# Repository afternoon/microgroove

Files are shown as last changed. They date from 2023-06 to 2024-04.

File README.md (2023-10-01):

# Microgroove

8-track open-source hardware MIDI sequence generator.

- Machines offer different ways to generate sequences: random melodies, Euclidean rhythms, rhythms 
  from Mutable Instruments' Grids.
- Tweak parameters to explore new ideas, or to perform live.
- Quantize melodies to scales.
- Add swing and groove.
- Create interplay between sequences, like call-and-response, or ABAC structures.

## Why?

The modular world has some amazing tools to create interesting sequences: Turing Machine, Mutable
Instruments Grids, Mimetic Digitalis, Knight's Gallop, and so many more. The software ecosystem does
too, plugins like Stepic, modules in VCV Rack, and so many Max for Live experiments. In the desktop
MIDI hardware world, we're short on options (kudos to the Torso T1 for changing that), and that's
where I like to jam. I built Microgroove to bring some interesting sequencing ideas into a desktop
MIDI setup.

Microgroove is also a platform for experimentation. Trying new sequencing ideas is fast: create a
software change, flash it to the device next to you and start playing. Open sourcing the entire
device means anyone can extend or adapt it.

## Caution

Microgroove is a DIY electronic device that connects to other hardware. Please be careful if you're
working on the electronics yourself, or connecting to expensive equipment. I can't guarantee that
Microgroove won't break your gear.

## Quickstart

Connect at least one instrument to MIDI out, for example, a synth or a drum machine.

Connect a device with a sequencer to MIDI in. Microgroove doesn't have its own clock or transport
controls. It expects another device to be the master clock.

Microgroove's Track 1 is set to MIDI channel 1 by default. Set one of your instruments to listen to 
this channel, or change it from the track page.

Press play on your master sequencer. Microgroove will start playing a
randomly-generated 8-step sequence on MIDI channel 1.

Microgroove's MIDI out provides soft MIDI thru. Any MIDI notes coming from your
master sequencer will also be sent to your instruments.

### Tweak

Microgroove's philosophy is that generating a sequence and tweaking it is a
great way to create ideas. Use `[ENCODER1]` to `[ENCODER6]` to change
parameters. Use the `[TRACK]`, `[RHYTHM]` and `[MELODY]` buttons to change
between parameter pages. Press `[TRACK]` to cycle between the Track and
Sequence pages, `[RHYTHM]` to cycle between Rhythm and Groove pages, `[MELODY]`
for Melody and Harmony pages.

Each page lets you control an aspect of the current track, or the overall sequence.

- Track: Change rhythm and melody machines, length, time division and MIDI
  channel for the current track. Use `[ENCODER3]` to switch between tracks.
- Sequence: Set swing for all tracks (MPC format).
- Rhythm: Parameters for the selected rhythm machine.
- Groove: Set a part for this track, masking areas of the pattern.
- Melody: Parameters for the selected melody machine.
- Harmony: Quantize the melody to scale and key.

Choose rhythm and melody machines for each track, both are random by default.

To switch tracks, press `[TRACK]` to go to the Track page and choose a track
with `[ENCODER3]`. Tracks 2-8 are disabled by default. Choose a MIDI channel to
enable them.

Parts allow you to set up multiple tracks to play together in structures like
call-and-response or ABAC. Try setting Track 1 to `CALL` and Track 2 to
`RESP`, with all other parameters the same.

## Hardware

Microgroove is a simple device based around the Raspberry Pi Pico microcontroller. Building your own
should be straightforward (I knew nothing about electronics before I built it). The parts are fairly
standard and easy to get hold of from a few different electronics vendors, for example Pi Hut in the
UK or Adafruit in the US, and many more. You can build the device on a breadboard, or solder to
something like a [protoboard](https://www.adafruit.com/product/4785) and mount inside a laser-cut
case.

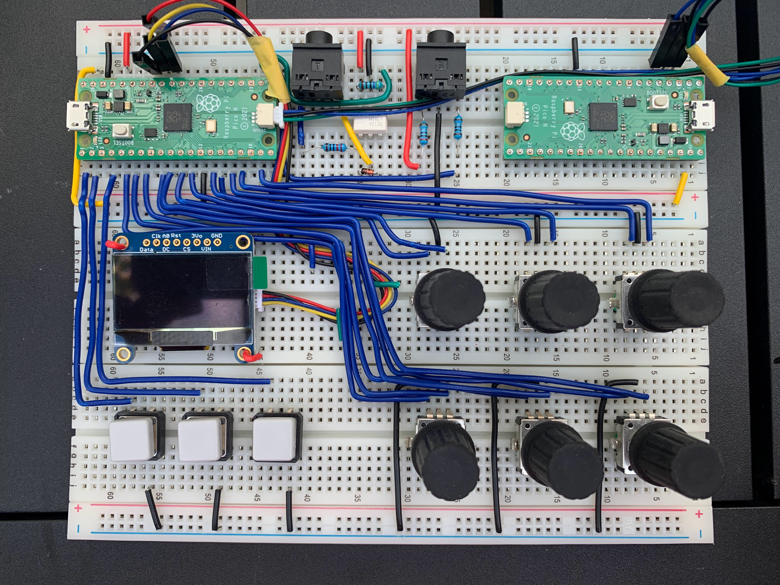
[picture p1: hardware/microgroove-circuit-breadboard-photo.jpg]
Early Microgroove build on a breadboard


### Components

| Component | Quantity |
|--- | --- |
| [Raspberry Pi Pico](https://www.raspberrypi.com/products/raspberry-pi-pico/) | 1 |
| [Adafruit 128x64 1.3" Monochrome OLED](https://www.adafruit.com/product/938) | 1 |
| [Cherry MX-compatible key](https://thepihut.com/products/kailh-mechanical-key-switches-clicky-white-10-pack) | 4 |
| [Cherry MX keycap](https://thepihut.com/products/relegendable-plastic-keycaps-for-mx-compatible-switches-5-pack) | 4 |
| [PEC11R rotary encoders](https://www.digikey.co.uk/en/products/detail/bourns-inc/PEC11R-4215F-S0024/4499665) | 6 |
| [TRS minijacks](https://thepihut.com/products/breadboard-friendly-3-5mm-stereo-headphone-jack) | 2 |
| [H11L1 optoisolator](https://www.digikey.co.uk/en/products/detail/onsemi/H11L1TVM/401266) | 1 |
| [1N914 diode](https://www.digikey.co.uk/en/products/detail/onsemi/1N914/978749) | 1 |
| 470Ω resistor | 1 |
| 220Ω resistor | 1 |
| 33Ω resistor | 1 |
| 10Ω resistor | 1 |
| Breadboard/protoboard | 2 |

### Build

This diagram shows the breadboard layout for Microgroove.

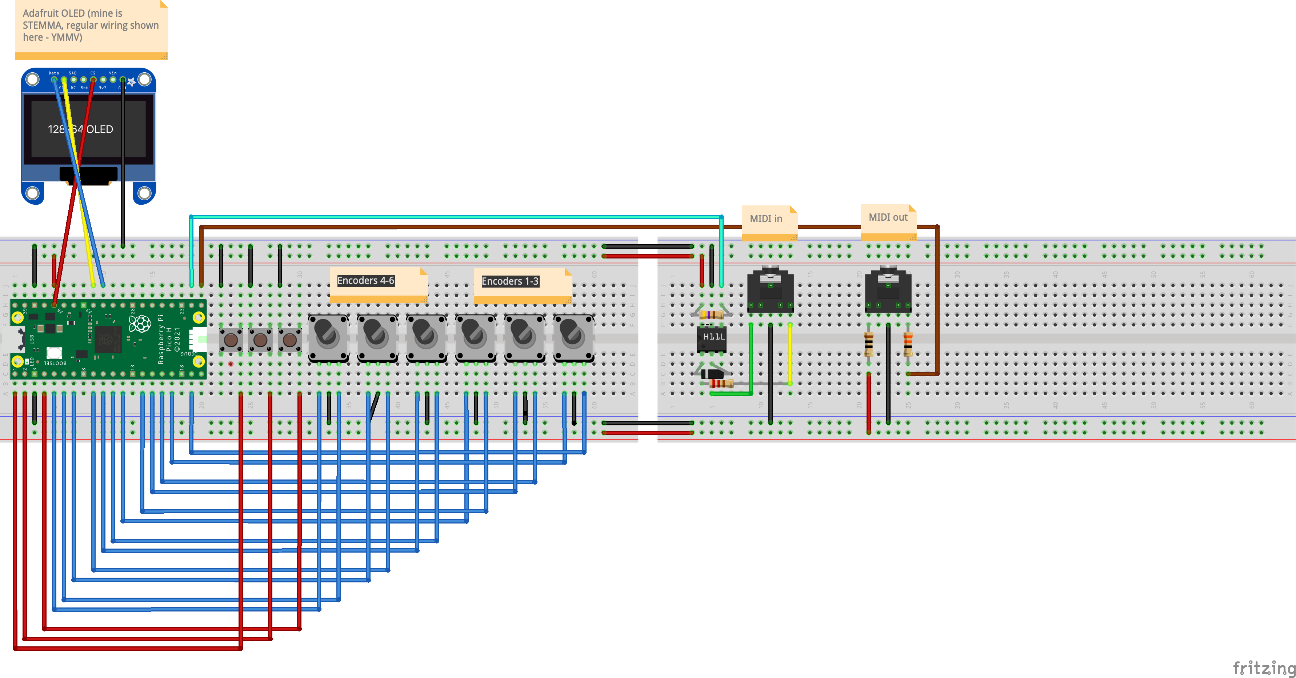
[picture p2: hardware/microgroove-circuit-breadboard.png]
Microgroove components shown on a breadboard


(If you want to build on a breadboard, you can get the Pico H, which has headers soldered on and
slots right on.)

See the [Fritzing
file](https://github.com/afternoon/microgroove/blob/main/hardware/microgroove-circuit.fzz) to view
the components and their connections. There is also a schematic view, but it is currently a mess.

The OLED display, keys and encoders connect directly to pins on the Pico.

The MIDI section is also fairly simple. They are based on diyelectromusic's
[MIDI in](https://diyelectromusic.wordpress.com/2021/02/15/midi-in-for-3-3v-microcontrollers/) and
[MIDI out](https://diyelectromusic.wordpress.com/2021/01/23/midi-micropython-and-the-raspberry-pi-pico/)
circuits (thanks Kevin!). You can use TRS minijacks like me, or classic MIDI DIN jacks. Either way,
check the pinouts for the components you purchase carefully. Wrong wiring here might damage your
gear.

### Case

The case is laser-cut. I used 3mm ply. You can find
the [design as an SVG file
here](https://github.com/afternoon/microgroove/blob/main/hardware/microgroove-case-lasercut.svg).

The SVG file was creating in Tinkercad. You can [access the model
here](https://www.tinkercad.com/things/e7vA3MJyz0E-microgroove-box). If you would like to make
your own modifications, you can clone the model in Tinkercad and customise it.

When cut, the case pieces slot together, and the components screw or glue to the case with 
standoffs and M2 or M3 screws.

If you don't have access to a laser cutter, you should be able to find cutting services online.

## Firmware

The Microgroove firmware is written in Rust using the [RTIC](https://rtic.rs)
real-time framework. RTIC is truly wonderful. It lets us write clean Rust code
which multitasks with timing accurate to a few microseconds.

The app loosely follows the MVC architecture. The `microgroove_sequencer` library crate implements
the model. In the `microgroove_app` binary crate, the `display` module implements the view, while
the`app` module implements the controller.

Conceptually Microgroove is inspired by Elektron's machines, which make it fast to create and
manipulate musical ideas (the UI borrows Elektron's pages + encoders paradigm), and from modular,
which allows different task-specific components to be composed into a system. Different `Machine`s
can be combined to change how the sequence is generated.

The Machine concept is somewhat inspired by modular, where different modules can generate the
rhythm or the melody, or process it.

The code is split across two crates to allow the model and logic code to be platform-independent,
and therefore testable.

### Data model

A set of `struct`s in the `microgroove_sequencer` crate implement the data model.

- The top-level object is an instance of `Sequencer`.
- A `Sequencer` has many `Track`s. `Track` has a length, time division, MIDI channel, etc, and a
  `Sequence`.
- `Sequence` is a wrapper around a `Vec` of `Step`s, providing a grammar of methods for
  manipulating sequences in useful ways, e.g. setting the note numbers for steps from a `Vec` of
  `Note`s.
- `Step` has a `Note`, velocity, length and delay.
- `Note` is an `enum` of all MIDI note numbers.

Sequence generation is implemented by the `SequenceGenerator` struct. This is exposed to the RTIC
application separately from the data model, to allow the app to control how and when concrete
sequences are generated. A `SequenceGenerator` object has two `Machine`s. One to generate the rhythm
and a second to generate a melody. `Machine`s have an `apply` method which takes a `Sequence` and
transforms it. The process of generating a sequence is implemented as a pipeline in
`SequenceGenerator::generate`. A default `Sequence` is created and transformed by several
`Machine`s in order. The `Sequence` is then passed to a quantizer and to logic which applies parts -
removing steps from parts of the sequence.

### Building the firmware

If you haven't already, [install Rust](https://www.rust-lang.org/tools/install). If you aren't yet
familiar with Rust, I recommend reading the [Rust Book](https://doc.rust-lang.org/book/) to learn
the language.

Microgroove requires Rust nightly (it uses the
[linked_list_allocator](https://crates.io/crates/linked_list_allocator) crate, which requires the
`AllocRef` trait only in the nightly API). You'll also need to install the `thumbv6m-none-eabi`
target, which allows compilation for the Pi Pico's ARM Cortex-M0+ CPU, and
[cargo-embed](https://crates.io/crates/cargo-embed) which extends `cargo` with an `embed` command to
flash binaries to embedded devices.

```
$ rustup toolchain install nightly
$ rustup target add thumbv6m-none-eabi
$ cargo install cargo-embed
```

You can check your setup by running the `microgroove_sequencer` crate's unit tests.

```
$ cd firmware/microgroove_sequencer
$ cargo test
```

Connect the Pi Pico to your computer with USB and use `cargo-embed` to flash the app to your device.

```
$ cd ../microgroove_app
$ cargo embed
```

Your Microgroove should now be ready to play!

### Debugging

Serial output will be displayed on the console. See the
[cargo-embed](https://crates.io/crates/cargo-embed) docs for information on how to run GDB.

You can also use `probe-run` to flash binaries, but this requires a debug probe (which can be a 2nd
Pi Pico).

## Get in touch

Microgroove is still young and evolving fast. I'm be really interested to help out if you would like to build a device or contribute. I'd love to get your feedback on the process and also on how the device is to play, whether it’s fun, if you find the sequences in generates useful, what would make it more useful, and so on.

If you have feedback, ideas or questions, 
head over to the [discussions section](https://github.com/afternoon/microgroove/discussions)
or contact me at [ben@ben2.com](mailto:ben@ben2.com).

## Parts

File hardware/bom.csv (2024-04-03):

Reference | Value | Datasheet | Footprint | Qty | DNP
D1 | 1N914 | http://www.vishay.com/docs/85622/1n914.pdf | Diode_THT:D_DO-35_SOD27_P7.62mm_Horizontal | 1
DS1 | NHD-2.7-12864WDW3 | https://componentsearchengine.com/Datasheets/1/NHD-2.7-12864WDW3.pdf | NHD-2.7-12864WDW3:NHD2712864WDW3 | 1
J1 | UJ2-MIBH-4-SMT-TR | https://www.cuidevices.com/product/resource/uj2-mibh-4-smt.pdf | UJ2-MIBH-4-SMT-TR:CUIDEVICES_UJ2-MIBH-4-SMT-TR | 1
J2,J3 | SJ1-3513 | https://www.cuidevices.com/product/resource/sj1-351x.pdf | SJ1_3513:CUI_SJ1-3513 | 2
R1 | 470 | ~ | Resistor_THT:R_Axial_DIN0207_L6.3mm_D2.5mm_P10.16mm_Horizontal | 1
R2 | 220 | ~ | Resistor_THT:R_Axial_DIN0207_L6.3mm_D2.5mm_P10.16mm_Horizontal | 1
R3 | 33 | ~ | Resistor_THT:R_Axial_DIN0207_L6.3mm_D2.5mm_P10.16mm_Horizontal | 1
R4 | 10 | ~ | Resistor_THT:R_Axial_DIN0207_L6.3mm_D2.5mm_P10.16mm_Horizontal | 1
SW1,SW2,SW3,SW4,SW5,SW6 | RotaryEncoder | https://www.bourns.com/docs/Product-Datasheets/PEC11R.pdf | PEC11R_4215F_S0024:XDCR_PEC11R-4215F-S0024 | 6
SW7,SW8,SW9,SW10,SW11 | TL1100F160Q6JBLK | TL1100F160Q6JBLK | footprints:SW4_TL1100F160Q6JBLK_EWI | 5
U1 | Pico | https://datasheets.raspberrypi.com/pico/pico-datasheet.pdf | MCU_RaspberryPi_and_Boards:RPi_Pico_SMD_TH | 1
U2 | H11L1 | https://www.onsemi.com/pub/Collateral/H11L3M-D.PDF | Package_DIP:DIP-6_W7.62mm | 1

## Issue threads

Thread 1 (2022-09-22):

Track param number doesn't update

afternoon, 2022-09-22:
In param table, track number is always 1.

Closed 2023-01-14.

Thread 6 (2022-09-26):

Allow arbitrary number of Params

afternoon, 2022-09-26:
Currently, each Machine has 6 Params (the number of encoders on the dev board). If fewer Params are required, they can be marked as disabled. Putting Params in e.g. a vector or a list would simplify the code and allow Machines to have more than 6 Params. In this case, the UI should support paging through the Param list, e.g. by pressing an input mode button repeatedly (the pattern used on Elektron machines).

Closed 2023-01-14.

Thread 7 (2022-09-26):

`TuringMachine` sequences do not loop correctly if length is not 16

afternoon, 2022-09-26:
`TuringMachine` should generate sequences which loop if `prob` is 0. Currently the implementation of `shift_bits()` uses all the bits of a `uint16t`, which means the sequence will only loop after 16 steps.

Expected behaviour:

1. At startup, the sequencer should generate a sequence of length `length`.
2. When the sequencer progresses, the `PROB` param should control the likelihood of the sequence changing.
3. The sequence can change at each step.
4. If the sequence changes, the UI should still show previous steps as they were played, and future steps should be updated with new values.
5. If `PROB` is at min or max, then the sequence displayed by the UI and the notes sent should be the same.
6. If `PROB` is at min or max, then the sequence should loop after `length` or `2 * length` steps.

Requirements:

1. Some way to get the full sequence (steps `0..length`).
2. Some way to get a suffix of the sequence, and write that over the invalidated suffix.
3. Some way to trigger the shifting of bits per-step.
4. The `Machine` API should be as clean and simple as possible.

Possible approaches:

1. Machine API has only `Note next()` method
   a. Track/Player implementation calls `next` `length` times to build a sequence or a sequence suffix.
   b. Pro: Simple API, Player/Track internals do the bookkeeping
   c. Con: next is destructive, subsequent calls, e.g. to generate different suffixes as params are tweaked, will change the sequence, this will be hard to predict for the user.
2. Machine API has separate methods to mutate and access the sequence (for a single note or string of notes).
   a. Pro:
   a. Con: Machine API has more methods = more work for machine implementors
   a. Con: Because bit flips are stochastic, UI will never actually display the real sequence if PROB is not at min or max.

Closed 2023-01-14.

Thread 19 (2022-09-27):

Player always plays 16 steps

afternoon, 2022-09-27:
- Need to track current step per-`Track` - `Track::tick()`?
- Must reset each `Track` from `start_playing`

Closed 2023-01-14.

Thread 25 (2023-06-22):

Integrate the NeoKey 1x4

afternoon, 2023-06-22:
[Adafruit's NeoKey 1x4](https://www.adafruit.com/product/4980) is a PCB that holds 4 Cherry MX keys and 4 NeoPixels (RGB LEDs). Clicky keys are really nice (I love the Elektron ones), colourful LEDs are really nice.

The NeoKey talks Adafruit's Seesaw protocol over I2C. The button state can be read by writing a command and then doing a read. A short pause is needed between these. Adafruit suggest 250us.

There are a couple of Seesaw crates available, but both use longer delays. This leads to the device locking up, as the key state is read every few ms. The Seesaw protocol is pretty simple, so the way to go might be to just do I2C write and read calls directly in the RTIC tasks. E.g.:

```
fn task1() {
  send_get_key_state_command();
  task2::spawn_after(READ_DELAY_US);
}

fn task2 {
  read_response();
}
```

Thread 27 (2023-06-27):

Press button to randomise

afternoon, 2023-06-27:
Currently, sequences are regenerated whenever a parameter is changed. For sequence generators which have some randomness as an input, this means that they change dramatically on each parameter change. This makes it impossible to generate a sequence and iterate upon it. For example, by cutting a 16-step sequence down to 8 steps.

It should be possible to control when regeneration happens and which elements are randomised. Some example scenarios:

1. Randomise only melody notes
2. Randomise groove (step velocities)
3. Randomise everything to start a new idea
4. Randomise only one parameter

Probably this could work as follows:

1. Go to the Melody page, press the `[RAND]` button
2. Go to the Groove page, press `[RAND]`
3. Long-press `[RAND]`
4. Hold `[RAND]` and tweak the encoder for the param(s) you want to randomise

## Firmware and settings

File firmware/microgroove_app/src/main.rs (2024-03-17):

#![no_std]
#![no_main]

mod display;
mod encoder;
mod input;
mod midi;
mod peripherals;

use panic_probe as _;

// RTIC app module runs the app as a set of concurrent tasks modifying shared state
// this module is responsible for interfacing with the hardware
#[rtic::app(
    device = rp_pico::hal::pac,
    peripherals = true,
    dispatchers = [USBCTRL_IRQ, DMA_IRQ_0, DMA_IRQ_1, PWM_IRQ_WRAP]
)]
mod app {
    use alloc_cortex_m::CortexMHeap;
    use core::fmt::Write;
    use debouncr::{debounce_8, Debouncer, Edge, Repeat8};
    use defmt::{self, debug, error, info, trace};
    use defmt_rtt as _;
    use embedded_hal::digital::v2::InputPin;
    use fugit::MicrosDurationU64;
    use heapless::{String, Vec};
    use midi_types::MidiMessage;
    use nb::block;
    use rp_pico::hal::timer::{monotonic::Monotonic, Alarm0};

    use crate::{
        display::{self, PerformView},
        encoder::encoder_array::EncoderArray,
        input::{self, InputMode},
        midi,
        peripherals::{
            setup, ButtonMelodyPin, ButtonRhythmPin, ButtonTrackPin, Display, MidiIn, MidiOut,
        },
    };
    use microgroove_sequencer::{
        machine_resources::MachineResources,
        sequence_generator::SequenceGenerator,
        sequencer::{ScheduledMidiMessage, Sequencer},
        Track, TRACK_COUNT,
    };

    #[global_allocator]
    static ALLOCATOR: CortexMHeap = CortexMHeap::empty();
    const HEAP_SIZE_BYTES: usize = 8 * 1024;

    // how often to read button state
    const BUTTON_READ_INTERVAL: MicrosDurationU64 = MicrosDurationU64::millis(5);

    // how often to poll encoders for position updates
    const ENCODER_READ_INTERVAL: MicrosDurationU64 = MicrosDurationU64::millis(2);

    // time between each display render
    // this is the practical upper bound for drawing and flushing a frame to the oled
    // at 40ms, the frame rate will be 25 FPS
    // we want the lowest frame rate that looks acceptable, to provide the largest budget for
    // render times
    const DISPLAY_UPDATE_INTERVAL: MicrosDurationU64 = MicrosDurationU64::millis(40);

    /// Define RTIC monotonic timer. Also used for defmt.
    #[monotonic(binds = TIMER_IRQ_0, default = true)]
    type TimerMonotonic = Monotonic<Alarm0>;

    /// RTIC shared resources.
    #[shared]
    struct Shared {
        current_track: u8,

        /// Sequencer big-ball-of-state
        sequencer: Sequencer,

        /// Current page of the UI.
        input_mode: InputMode,

        // set of SequenceGenerators, one for each `Track` in `Sequencer`
        sequence_generators: Vec<SequenceGenerator, TRACK_COUNT>,
    }

    /// RTIC local resources.
    #[local]
    struct Local {
        /// MIDI input port (1 half of the split UART).
        midi_in: MidiIn,

        /// MIDI output port (1 half of the split UART).
        midi_out: MidiOut,

        /// Interface to the display.
        display: Display,

        /// Pin for button the [TRACK] button
        button_track_pin: ButtonTrackPin,

        /// Pin for button the [RHYTHM] button
        button_rhythm_pin: ButtonRhythmPin,

        /// Pin for button the [MELODY] button
        button_melody_pin: ButtonMelodyPin,

        /// Debounce state for [TRACK] button
        button_track_state: Debouncer<u8, Repeat8>,

        /// Debounce state for [RHYTHM] button
        button_rhythm_state: Debouncer<u8, Repeat8>,

        /// Debounce state for [MELODY] button
        button_melody_state: Debouncer<u8, Repeat8>,

        // encoders
        encoders: EncoderArray,

        // context object for machines to use in sequence generation
        machine_resources: MachineResources,
    }

    /// RTIC init method sets up the hardware and initialises shared and local resources.
    #[init]
    fn init(ctx: init::Context) -> (Shared, Local, init::Monotonics) {
        info!("[init] hello world!");

        // initialise allocator for dynamic structures (machines, params, etc)
        unsafe {
            ALLOCATOR.init(cortex_m_rt::heap_start() as usize, HEAP_SIZE_BYTES);
            debug!(
                "[init] heap_start={} heap_size_bytes={}",
                cortex_m_rt::heap_start() as usize,
                HEAP_SIZE_BYTES
            );
        }

        // configure RTIC monotonic as source of timestamps for defmt
        defmt::timestamp!("{=u64:us}", {
            monotonics::now().duration_since_epoch().to_micros()
        });

        // create a device wrapper instance and grab some of the peripherals we need
        let (midi_in, midi_out, mut display, buttons, encoders, rosc, monotonic_timer) =
            setup(ctx.device);
        let (button_track_pin, button_rhythm_pin, button_melody_pin) = buttons;

        // create bounce state trackers for each button
        let button_track_state = debounce_8(false);
        let button_rhythm_state = debounce_8(false);
        let button_melody_state = debounce_8(false);

        // create a vec of `SequenceGenerator`s, we'll use these to generate sequences for our
        // tracks.
        let mut sequence_generators: Vec<SequenceGenerator, TRACK_COUNT> = Vec::new();
        for _i in 0..TRACK_COUNT {
            sequence_generators
                .push(SequenceGenerator::default())
                .expect("adding SequenceGenerator to vec should succeed");
        }

        // create a new sequencer and build the first track
        let mut sequencer = Sequencer::default();
        let mut generator = SequenceGenerator::default();
        let mut machine_resources = MachineResources::new(rosc);
        let mut new_track = Track::default();
        generator.generate(&mut machine_resources);
        new_track.sequence = generator.apply(new_track.length);
        sequencer.enable_track(0, new_track);

        // show a splash screen for a bit
        display::render_splash_screen_view(&mut display)
            .expect("render_splash_screen_view should succeed");

        // start scheduled tasks to read buttons, read encoders and update display
        read_buttons::spawn().expect("read_buttons::spawn should succeed");
        read_encoders::spawn().expect("read_encoders::spawn should succeed");
        update_display::spawn().expect("update_display::spawn should succeed");

        info!("[init] complete 🤘");

        (
            Shared {
                input_mode: Default::default(),
                current_track: 0,
                sequencer,
                sequence_generators,
            },
            Local {
                midi_in,
                midi_out,
                display,
                button_track_pin,
                button_rhythm_pin,
                button_melody_pin,
                button_track_state,
                button_rhythm_state,
                button_melody_state,
                encoders,
                machine_resources,
            },
            init::Monotonics(monotonic_timer),
        )
    }

    /// Handle MIDI input. Triggered by a byte being received on UART0.
    #[task(
        binds = UART0_IRQ,
        priority = 4,
        shared = [sequencer],
        local = [midi_in]
    )]
    fn uart0_irq(mut ctx: uart0_irq::Context) {
        let start = monotonics::now();
        trace!("[uart0_irq] start");

        // read those sweet sweet midi bytes!
        // TODO do we need the block! here?
        if let Ok(message) = block!(ctx.local.midi_in.read()) {
            ctx.shared.sequencer.lock(|sequencer| match message {
                MidiMessage::TimingClock => {
                    trace!("[midi] clock");
                    let now_us = monotonics::now().duration_since_epoch().to_micros();
                    let messages = sequencer.advance(now_us);
                    for message in messages {
                        match message {
                            ScheduledMidiMessage::Immediate(message) => {
                                if let Err(_err) = midi_send::spawn(message) {
                                    error!("could not spawn midi_send for immediate message")
                                }
                            }
                            ScheduledMidiMessage::Delayed(message, delay) => {
                                if let Err(_err) = midi_send::spawn_after(delay, message) {
                                    error!("could not spawn midi_send for delayed message")
                                }
                            }
                        }
                    }
                }
                MidiMessage::Start => {
                    info!("[midi] start");
                    sequencer.start_playing();
                }
                MidiMessage::Stop => {
                    info!("[midi] stop");
                    sequencer.stop_playing();
                }
                MidiMessage::Continue => {
                    info!("[midi] continue");
                    sequencer.continue_playing();
                }
                _ => trace!("[midi] UNKNOWN"),
            });

            // pass received message to midi out ("soft thru")
            match midi_send::spawn(message) {
                Ok(_) => (),
                Err(_) => error!("could not spawn midi_send to pass through message"),
            }
        }

        trace!(
            "[uart0_irq] elapsed_time={}",
            (monotonics::now() - start).to_micros()
        );
    }

    /// Send a MIDI message. Implemented as a task to allow cooperative multitasking with
    /// higher-pri tasks.
    #[task(
        priority = 3,
        capacity = 64,
        local = [midi_out]
    )]
    fn midi_send(ctx: midi_send::Context, message: MidiMessage) {
        trace!("midi_send");
        midi::log_message(&message);
        ctx.local
            .midi_out
            .write(&message)
            .expect("midi_out.write(message) should succeed");
    }

    /// Check state of buttons, debouncing inputs, and update the `input_mode` shared resource.
    #[task(
        priority = 4,
        shared = [input_mode],
        local = [button_track_pin, button_rhythm_pin, button_melody_pin, button_track_state, button_rhythm_state, button_melody_state]
    )]
    fn read_buttons(mut ctx: read_buttons::Context) {
        let start = monotonics::now();
        trace!("[read_buttons] start");

        // for each button
        let track_pressed = ctx
            .local
            .button_track_pin
            .is_low()
            .expect("should get track button state");
        let track_edge = ctx.local.button_track_state.update(track_pressed);
        if track_edge == Some(Edge::Rising) {
            info!("[TRACK] pressed");
            ctx.shared.input_mode.lock(|input_mode| {
                *input_mode = match *input_mode {
                    InputMode::Track => InputMode::Sequence,
                    _ => InputMode::Track,
                }
            });
        }

        let rhythm_pressed = ctx
            .local
            .button_rhythm_pin
            .is_low()
            .expect("should get rhythm button state");
        let rhythm_edge = ctx.local.button_rhythm_state.update(rhythm_pressed);
        if rhythm_edge == Some(Edge::Rising) {
            info!("[RHYTHM] pressed");
            ctx.shared.input_mode.lock(|input_mode| {
                *input_mode = match *input_mode {
                    InputMode::Rhythm => InputMode::Groove,
                    _ => InputMode::Rhythm,
                }
            });
        }

        let melody_pressed = ctx
            .local
            .button_melody_pin
            .is_low()
            .expect("should get melody button state");
        let melody_edge = ctx.local.button_melody_state.update(melody_pressed);
        if melody_edge == Some(Edge::Rising) {
            info!("[MELODY] pressed");
            ctx.shared.input_mode.lock(|input_mode| {
                *input_mode = match *input_mode {
                    InputMode::Melody => InputMode::Harmony,
                    _ => InputMode::Melody,
                }
            });
        }

        read_buttons::spawn_after(BUTTON_READ_INTERVAL).expect("should spawn read_buttons task");

        trace!(
            "[read_buttons] elapsed_time={}",
            (monotonics::now() - start).to_micros()
        );
    }

    /// Check encoders for position changes.
    /// Reading every 1ms removes some of the noise vs reading on each interrupt.
    #[task(
        priority = 4,
        shared = [input_mode, current_track, sequencer, sequence_generators],
        local = [encoders, machine_resources],
    )]
    fn read_encoders(ctx: read_encoders::Context) {
        let start = monotonics::now();
        trace!("[read_encoders] start");

        if let Some(_changes) = ctx.local.encoders.update() {
            (
                ctx.shared.input_mode,
                ctx.shared.current_track,
                ctx.shared.sequencer,
                ctx.shared.sequence_generators,
            )
                .lock(
                    |input_mode, current_track, sequencer, sequence_generators| {
                        input::apply_encoder_values(
                            ctx.local.encoders.take_values(),
                            *input_mode,
                            current_track,
                            sequencer,
                            sequence_generators,
                        )
                        .expect("should be able to apply encoder values");
                    },
                )
        }

        // read again in 1ms
        read_encoders::spawn_after(ENCODER_READ_INTERVAL)
            .expect("schedule read_encoders should succeed");

        trace!(
            "[read_encoders] elapsed_time={}",
            (monotonics::now() - start).to_micros()
        );
    }

    /// Update the display by rendering a view object. This method creates an instance of a view,
    /// passing in relevant data (which is copied). The view then takes care of rendering to the
    /// display. Rendering is time-consuming, because writing data across I2C is slow. Hence the
    /// work is offloaded to the `render_view` task, unlocking shared resources and allowing other
    /// tasks to interrupt the rendering.
    #[task(
        priority = 1,
        shared = [input_mode, current_track, sequencer, sequence_generators],
    )]
    fn update_display(ctx: update_display::Context) {
        let start = monotonics::now();
        trace!("[update_display] start");

        (
            ctx.shared.input_mode,
            ctx.shared.current_track,
            ctx.shared.sequencer,
            ctx.shared.sequence_generators,
        )
            .lock(
                |input_mode, current_track, sequencer, sequence_generators| {
                    let tick = sequencer.tick();
                    let maybe_track = sequencer
                        .tracks
                        .get_mut(*current_track as usize)
                        .expect("should get current track")
                        .as_mut();
                    let generator = sequence_generators
                        .get(*current_track as usize)
                        .expect("should get current sequence generator");
                    let part = generator.part();
                    let view = match maybe_track {
                        Some(track) => {
                            let sequence = Some(track.sequence.clone());
                            let active_step_num = Some(track.step_num(tick));
                            let machine_name = match input_mode {
                                InputMode::Rhythm => {
                                    Some(String::<10>::from(generator.rhythm_machine.name()))
                                }
                                InputMode::Melody => {
                                    Some(String::<10>::from(generator.melody_machine.name()))
                                }
                                _ => None,
                            };
                            let params = match input_mode {
                                InputMode::Track => track.params(),
                                InputMode::Sequence => sequencer.params(),
                                InputMode::Rhythm => generator.rhythm_machine.params(),
                                InputMode::Groove => generator.groove_params(),
                                InputMode::Melody => generator.melody_machine.params(),
                                InputMode::Harmony => generator.harmony_params(),
                            };
                            let param_data = Some(
                                params
                                    .iter()
                                    .map(|param| {
                                        let mut value_string = String::new();
                                        write!(value_string, "{}", param.value())
                                            .expect("should write param value to string buf");
                                        (String::<6>::from(param.name()), value_string)
                                    })
                                    .collect(),
                            );
                            PerformView {
                                input_mode: *input_mode,
                                playing: sequencer.playing(),
                                track_num: *current_track,
                                sequence,
                                part,
                                active_step_num,
                                machine_name,
                                param_data,
                            }
                        }
                        None => PerformView {
                            input_mode: *input_mode,
                            playing: sequencer.playing(),
                            track_num: *current_track,
                            sequence: None,
                            part,
                            active_step_num: None,
                            machine_name: None,
                            param_data: None,
                        },
                    };

                    render_view::spawn(view).expect("should be able to spawn_after display_update");
                },
            );

        update_display::spawn_after(DISPLAY_UPDATE_INTERVAL)
            .expect("should be able to spawn_after update_display");

        trace!(
            "[update_display] elapsed_time={}",
            (monotonics::now() - start).to_micros()
        );
    }

    #[task(
        priority = 1,
        local = [display]
    )]
    fn render_view(ctx: render_view::Context, view: PerformView) {
        let start = monotonics::now();
        trace!("[render_view] start");

        if let Err(_) = view.render(ctx.local.display) {
            error!("PerformView::render error");
        }

        trace!(
            "[render_view] elapsed_time={}",
            (monotonics::now() - start).to_micros()
        );
    }

    // idle task needed because default RTIC idle task calls wfi(), which breaks rtt
    // TODO disable in release mode
    #[idle]
    fn task_main(_: task_main::Context) -> ! {
        loop {
            cortex_m::asm::nop();
        }
    }
}

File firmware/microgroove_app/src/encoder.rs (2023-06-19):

pub mod positional_encoder {
    use core::fmt::Debug;
    use defmt::{error, trace};
    use rotary_encoder_hal::{Direction, Rotary};
    use rp_pico::hal::gpio::DynPin;

    pub struct PositionalEncoder {
        encoder: Rotary<DynPin, DynPin>,
        value: i8,
    }

    impl PositionalEncoder {
        pub fn new(mut pin_a: DynPin, mut pin_b: DynPin) -> PositionalEncoder {
            pin_a.into_pull_up_input();
            pin_b.into_pull_up_input();
            PositionalEncoder {
                encoder: Rotary::new(pin_a.into(), pin_b.into()),
                value: 0,
            }
        }

        /// Check the encoder state for changes. This should be called frequently, e.g.
        /// every 1ms. Returns a `Some` containing the encoder value if there have been
        /// changes, `None` otherwise.
        pub fn update(&mut self) -> Option<i8> {
            match self.encoder.update() {
                Ok(Direction::Clockwise) => {
                    trace!("[PositionalEncoder::update] Direction::Clockwise");
                    self.value += 1;
                    Some(self.value)
                }
                Ok(Direction::CounterClockwise) => {
                    trace!("[PositionalEncoder::update] Direction::CounterClockwise");
                    self.value -= 1;
                    Some(self.value)
                }
                Ok(Direction::None) => None,
                Err(_error) => {
                    error!("[PositionalEncoder::update] could not update encoder");
                    None
                }
            }
        }

        /// Get the value of the encoder, and then reset that to zero. This has the
        /// semantics of "I would like to know your value, which I will use to update my
        /// state, so you can then discard it."
        pub fn take_value(&mut self) -> Option<i8> {
            let value = self.value;
            if value == 0 {
                None
            } else {
                self.value = 0;
                Some(value)
            }
        }
    }

    impl Debug for PositionalEncoder {
        fn fmt(&self, f: &mut core::fmt::Formatter<'_>) -> core::fmt::Result {
            write!(f, "encoder")
        }
    }
}

pub mod encoder_array {
    use super::positional_encoder::PositionalEncoder;
    use heapless::Vec;

    pub const ENCODER_COUNT: usize = 6;

    /// An array of multiple `PositionalEncoders`.
    pub struct EncoderArray {
        encoders: Vec<PositionalEncoder, ENCODER_COUNT>,
    }

    impl EncoderArray {
        pub fn new(encoders: Vec<PositionalEncoder, ENCODER_COUNT>) -> EncoderArray {
            EncoderArray { encoders }
        }

        pub fn update(&mut self) -> Option<()> {
            let any_changes = self
                .encoders
                .iter_mut()
                .map(|enc| enc.update())
                .any(|opt| opt.is_some());
            if any_changes {
                Some(())
            } else {
                None
            }
        }

        pub fn take_values(&mut self) -> Vec<Option<i8>, ENCODER_COUNT> {
            self.encoders
                .iter_mut()
                .map(|enc| enc.take_value())
                .collect()
        }
    }
}

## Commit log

2022-10-14 Use trunk versions of rp-pico and rp2040-hal
2022-10-16 Track interval between MIDI ticks and use it to calculate note lengths
2022-10-17 PoC to render some stuff on an SSD1306-powered OLED display
2022-10-23 Change pins around, read buttons and encoders in ISR
2022-10-27 Switch to rotary-encoder-hal table-decoder version, fixes multiple increments
    [main.rs]
2022-10-31 Read all 6 encoders
2022-11-01 [1/n] Root causing failing button interrupts
    [main.rs]
2022-11-01 Revert main.rs to "spaghetti" version
    I found the issue - I hadn't connected the ground rail on my breadboard,
    so button presses were not properly grounding the pins. 🤦
    [main.rs]
2022-11-01 Use rp2040's ring oscillator peripheral to generate random numbers
    [main.rs]
2022-11-04 Remove no-longer-required button_repro.rs (it was a missing ground wire)
2022-11-05 [2/n] Yak-shaving type/lifetime/borrow errors
    [main.rs]
2022-11-10 [3/3] Move device setup to a single function
    I can't figure out how to get the ownership of pac right to split setup across multiple functions. X-(
2022-11-24 Show track disabled warning (&& add warning helper)
2022-11-28 Add SequenceProcessors which generate musical sequences, Params, which translate encoder input into arguments to SequenceProcessors, and Machines, which glue those two concepts together into somethin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
2022-11-28 Add global allocator, tidy up some errors
    [main.rs]
2022-11-30 Map encoder input to track/machine params
2022-12-01 Add Track Param definitions
2022-12-01 Allow device-agnostic code to be tested by splitting code into 2 crates, one for business logic and one for hardware-specific parts, e.g. the rtic app, display code, etc
2022-12-02 Display track number in header correctly
    [main.rs]
2022-12-04 Fix REALLY STUPID bug in encoder input handling
    It always went up.
    [encoder.rs, input.rs, main.rs]
2022-12-04 Track::apply_params() regenerates sequence
2022-12-05 Increment track num correctly and create new tracks when other params change
    [encoder.rs, input.rs, lib.rs]
2022-12-05 Set MIDI channel to track number on track creation
2022-12-05 Implement Default for InputMode, TimeDivision and Track
2022-12-05 Show current machine name in header
2022-12-05 Remove Track::new() and tidy up test names
2022-12-06 Fix bug in calculation of average tick duration (and thus tempo)
    [input.rs]
2022-12-06 MIDI channel is 0-indexed in track and 1-indexed in params 🤷
2022-12-07 Offload display rendering to a 2nd task, unlocking resources and making encoder and button reading and MIDI _FUCKIN TIGHT_
    [encoder.rs, input.rs, lib.rs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]
2022-12-07 Reorder track speed param values to be more natural
2022-12-15 Almost a rewrite...
    Introduce a new kind of machine which generates a random sequence...
    Which meant rewriting the Sequencer/Track/Machine structure to allow an
    RNG to be passed...
    Which required some conditional compilation to provide access to
    platform-specific RNGs...
    Which didn't require rewriting params, but honestly I had started that
    first and couldn't face unpicking the changes.
    Probably other stuff I've forgotten.
    [input.rs, lib.rs, main.rs]
2022-12-19 Fix off-by-one error in midi channel param handler
    [lib.rs]
2022-12-19 RandMelodyMachine generates notes in the specified range
    And add in the missing F#8 note! Eeeek.
    [lib.rs]
2022-12-19 Only reset machines if machine params have changed
    [input.rs]
2022-12-20 Euclidean. Groove. Machine. 🤘
2022-12-23 Add quantizer params to a 2nd page when pressing [MELODY]
    Also create 2nd pages for the [TRACK] and [RHYTHM] buttons, for global and groove params respectively. Will be used later for stuff like swing.
2022-12-23 Debounce button presses (so we can land on a specific param page reliably)
2023-01-13 Add a part param, which can be used to mute sections of a track, such that multiple tracks can be composed into structures like call and response, or ABAC
2023-06-19 Replace unwrap with expect in a bunch of places, and cargo fmt
    [encoder.rs, input.rs, main.rs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]
2023-06-19 Remove the alloc error handler, its no longer needed
    [main.rs]
2023-06-19 Move Rust firmware source to firmware subdirectory, create hardware subdir and add case and circuit diagrams
    [microgroove-circuit.fzz]
2023-06-20 Add photo of my breadboard prototype Microgroove
2023-06-20 [README] Show photo of my breadboard prototype Microgroove
2023-06-22 [README] Tidy up hardware build instructions and add BOM
    [microgroove-circuit.fzz]
2023-06-22 [README] Add keys and keycaps to BOM
2023-10-01 Remove NeoKey from docs and designs. It is dead to me.
    [microgroove-circuit.fzz]
2024-03-17 Add KiCAD schematic for v1.1 circuit (TRS Type A, PINs moved around for more PCB-friendly layout, hopefully)
    [microgroove.kicad_pcb, microgroove.kicad_sch]
2024-03-17 Ignore KiCAD's footprint cache file
2024-03-18 Add custom KiCAD symbol for the NHD-2.7-12864WDW3 2.7in OLED display
    [microgroove.kicad_sch]
2024-04-03 Add KiCAD symbol and footprint for NHD-2.7-12864WDW3 from Mouser
    [microgroove.kicad_sch]
2024-04-03 Add BOM file
    [bom.csv]
2024-04-03 Assign footprints for KiCAD schematic symbols
    [microgroove.kicad_sch]
2024-04-03 Add custom footprints for KiCAD schematic symbols
